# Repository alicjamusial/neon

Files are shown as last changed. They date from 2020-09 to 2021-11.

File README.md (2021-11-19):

# NEON - FT4232H Mini Module Adapter 

### about the project

 Neon is a PCB project designed as an adapter for FTDI FT4232H Mini Module board. It includes four two rows UART sockets (A, B, C, D) for easy plugging in logic analyzer and LEDs on both TX/RX and USB power supply. Its main goal is to improve the experience of using FTDI Mini Module and allow to quickly and easily debug any possible issues. It was designed using [KiCad](https://kicad.org/).

Version 1.0 is available [in the releases section](https://github.com/alicjamusial/neon/releases/tag/neon-v.1.0).

### usage
To be able to use Neon powered by USB two jumpers needs to be placed on the board (on J1 (3V3 & VIO) and J5 (VCC & VBUS) elements).

### license
Neon is available on Creative Commons Attribution Share Alike 4.0 International license (more in [license file](LICENSE.txt)). You are free to use it, modify it and produce as many of your own neons as you need :)

### assembled neon ✨

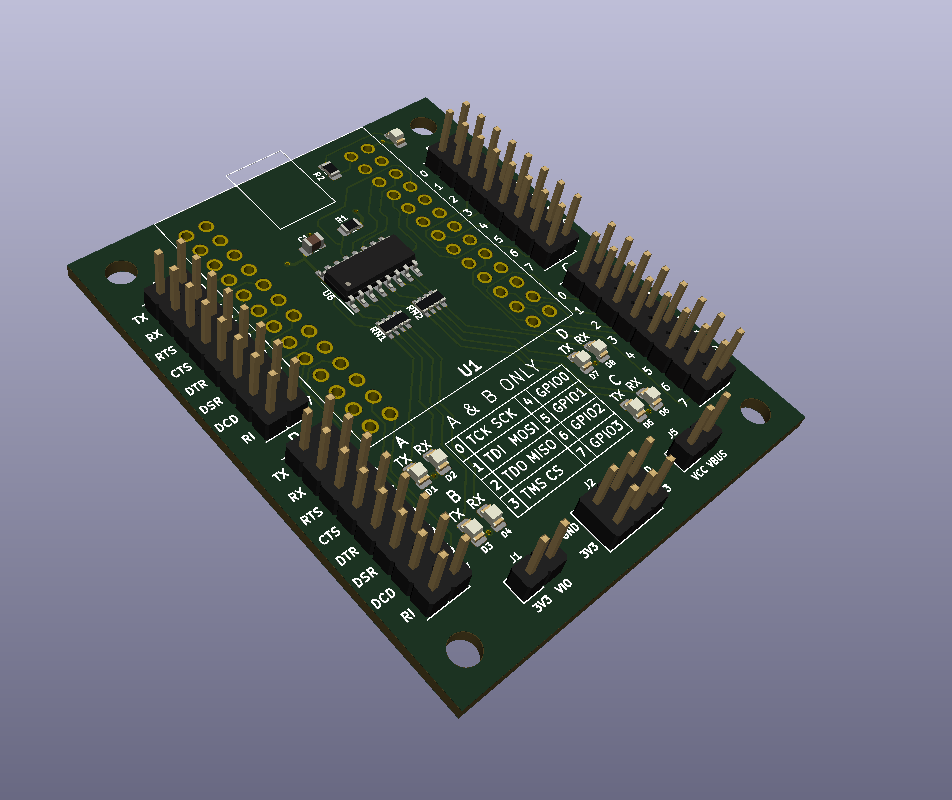
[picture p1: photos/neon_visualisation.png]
visualisation

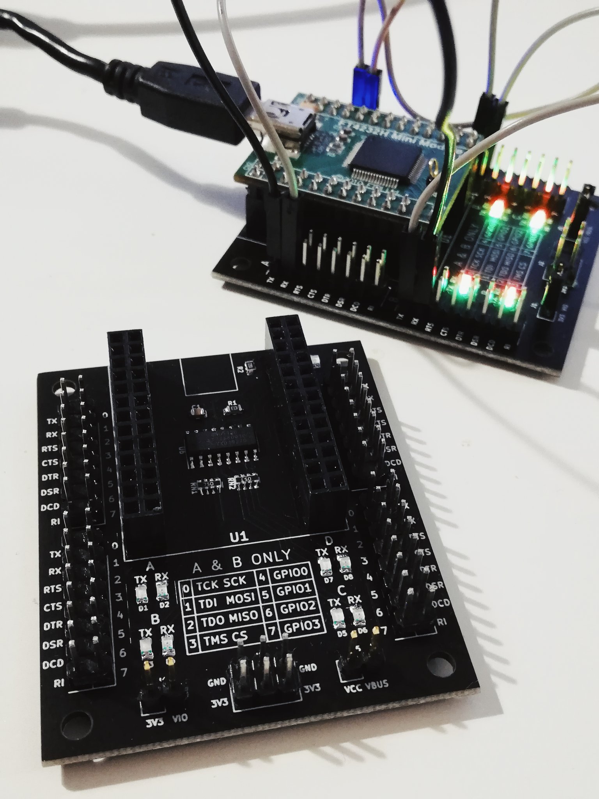
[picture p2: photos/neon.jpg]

gif

#### TODO in version 1.1
* label for D9 LED on board,
* labels for the directions of all LEDs on board,
* ...any ideas/fixes/improvements/PRs are welcomed :)

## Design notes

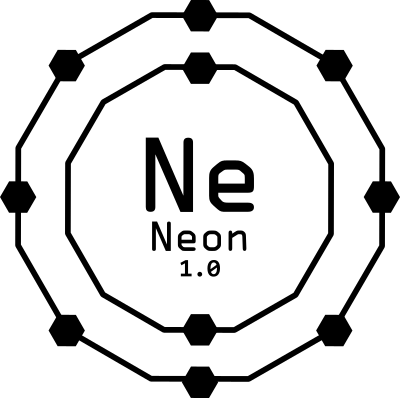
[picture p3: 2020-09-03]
NEON.png

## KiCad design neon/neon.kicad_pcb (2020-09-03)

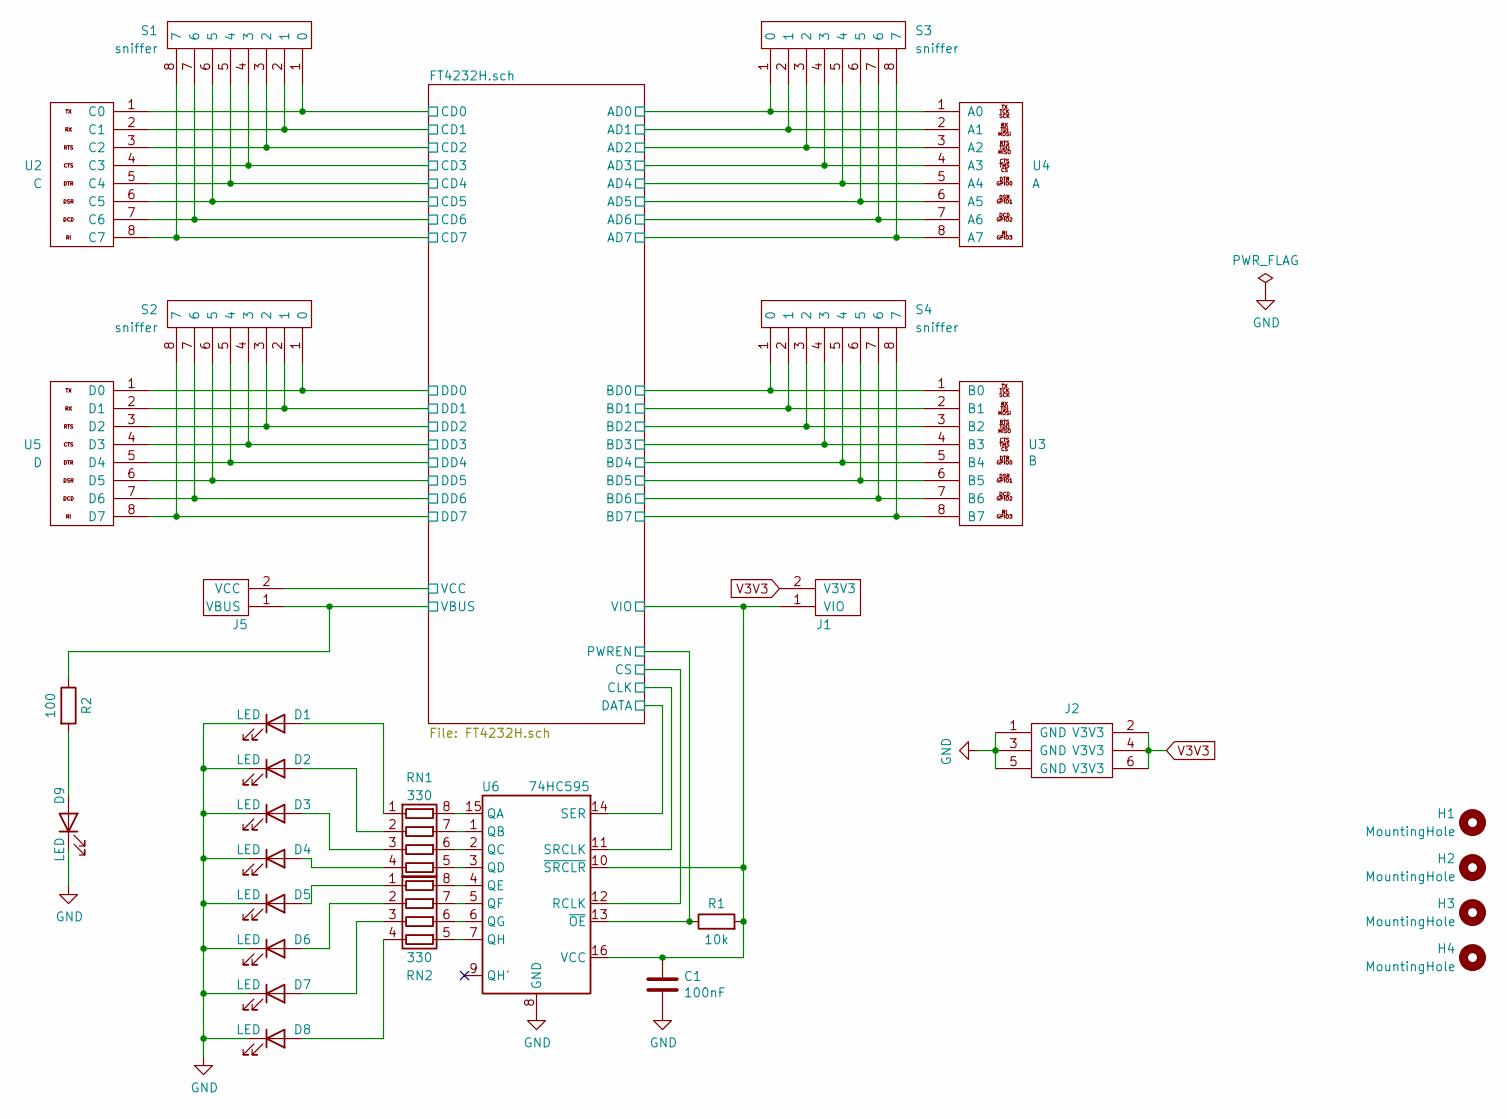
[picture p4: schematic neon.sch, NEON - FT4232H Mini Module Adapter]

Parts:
C1: 100nF; C_0805_2012Metric
D1, D2, D3, D4, D5, D6, D7, D8, D9: LED; LED_0805_2012Metric
H1, H2, H3, H4: MountingHole; MountingHole_3.2mm_M3
J1: V3V3-VIO; PinHeader_1x02_P2.54mm_Vertical
J2: 3xV3V3-GND; PinHeader_2x03_P2.54mm_Vertical
J5: VBUS-VCC; PinHeader_1x02_P2.54mm_Vertical
R1: 10k; R_0805_2012Metric
R2: 100; R_0805_2012Metric
RN1, RN2: 330; R_Array_Convex_4x0603
S1, S2, S3, S4: sniffer; PinHeader_1x08_P2.54mm_Vertical
U2: C; PinHeader_1x08_P2.54mm_Vertical
U3: B; PinHeader_1x08_P2.54mm_Vertical
U4: A; PinHeader_1x08_P2.54mm_Vertical
U5: D; PinHeader_1x08_P2.54mm_Vertical
U6: 74HC595; SOIC-16_3.9x9.9mm_P1.27mm

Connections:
/FT4232H.sch/AD0: S3.1 (0), U4.1 (A0); also elsewhere on the board
/FT4232H.sch/AD1: S3.2 (1), U4.2 (A1); also elsewhere on the board
/FT4232H.sch/AD2: S3.3 (2), U4.3 (A2); also elsewhere on the board
/FT4232H.sch/AD3: S3.4 (3), U4.4 (A3); also elsewhere on the board
/FT4232H.sch/AD4: S3.5 (4), U4.5 (A4); also elsewhere on the board
/FT4232H.sch/AD5: S3.6 (5), U4.6 (A5); also elsewhere on the board
/FT4232H.sch/AD6: S3.7 (6), U4.7 (A6); also elsewhere on the board
/FT4232H.sch/AD7: S3.8 (7), U4.8 (A7); also elsewhere on the board
/FT4232H.sch/BD0: S4.1 (0), U3.1 (B0); also elsewhere on the board
/FT4232H.sch/BD1: S4.2 (1), U3.2 (B1); also elsewhere on the board
/FT4232H.sch/BD2: S4.3 (2), U3.3 (B2); also elsewhere on the board
/FT4232H.sch/BD3: S4.4 (3), U3.4 (B3); also elsewhere on the board
/FT4232H.sch/BD4: S4.5 (4), U3.5 (B4); also elsewhere on the board
/FT4232H.sch/BD5: S4.6 (5), U3.6 (B5); also elsewhere on the board
/FT4232H.sch/BD6: S4.7 (6), U3.7 (B6); also elsewhere on the board
/FT4232H.sch/BD7: S4.8 (7), U3.8 (B7); also elsewhere on the board
/FT4232H.sch/CD0: S1.1 (0), U2.1 (C0); also elsewhere on the board
/FT4232H.sch/CD1: S1.2 (1), U2.2 (C1); also elsewhere on the board
/FT4232H.sch/CD2: S1.3 (2), U2.3 (C2); also elsewhere on the board
/FT4232H.sch/CD3: S1.4 (3), U2.4 (C3); also elsewhere on the board
/FT4232H.sch/CD4: S1.5 (4), U2.5 (C4); also elsewhere on the board
/FT4232H.sch/CD5: S1.6 (5), U2.6 (C5); also elsewhere on the board
/FT4232H.sch/CD6: S1.7 (6), U2.7 (C6); also elsewhere on the board
/FT4232H.sch/CD7: S1.8 (7), U2.8 (C7); also elsewhere on the board
/FT4232H.sch/CLK: U6.11 (SRCLK); also elsewhere on the board
/FT4232H.sch/CS: U6.12 (RCLK); also elsewhere on the board
/FT4232H.sch/DATA: U6.14 (SER); also elsewhere on the board
/FT4232H.sch/DD0: S2.1 (0), U5.1 (D0); also elsewhere on the board
/FT4232H.sch/DD1: S2.2 (1), U5.2 (D1); also elsewhere on the board
/FT4232H.sch/DD2: S2.3 (2), U5.3 (D2); also elsewhere on the board
/FT4232H.sch/DD3: S2.4 (3), U5.4 (D3); also elsewhere on the board
/FT4232H.sch/DD4: S2.5 (4), U5.5 (D4); also elsewhere on the board
/FT4232H.sch/DD5: S2.6 (5), U5.6 (D5); also elsewhere on the board
/FT4232H.sch/DD6: S2.7 (6), U5.7 (D6); also elsewhere on the board
/FT4232H.sch/DD7: S2.8 (7), U5.8 (D7); also elsewhere on the board
/FT4232H.sch/PWREN: R1.1, U6.13 (~OE); also elsewhere on the board
/FT4232H.sch/VBUS: J5.1 (VBUS), R2.1; also elsewhere on the board
/FT4232H.sch/VCC: J5.2 (VCC); also elsewhere on the board
/FT4232H.sch/VIO: C1.1, J1.1 (VIO), R1.2, U6.10 (~SRCLR), U6.16 (VCC); also elsewhere on the board
GND: C1.2, D1.1 (K), D2.1 (K), D3.1 (K), D4.1 (K), D5.1 (K), D6.1 (K), D7.1 (K), D8.1 (K), D9.1 (K), J2.1 (GND), J2.3 (GND), J2.5 (GND), U6.8 (GND); also elsewhere on the board
unnamed: D1.2 (A), RN1.1 (R1.1)
unnamed: D2.2 (A), RN1.2 (R2.1)
unnamed: D3.2 (A), RN1.3 (R3.1)
unnamed: D4.2 (A), RN1.4 (R4.1)
unnamed: D5.2 (A), RN2.1 (R1.1)
unnamed: D6.2 (A), RN2.2 (R2.1)
unnamed: D7.2 (A), RN2.3 (R3.1)
unnamed: D8.2 (A), RN2.4 (R4.1)
unnamed: D9.2 (A), R2.2
unnamed: RN1.5 (R4.2), U6.3 (QD)
unnamed: RN1.6 (R3.2), U6.2 (QC)
unnamed: RN1.7 (R2.2), U6.1 (QB)
unnamed: RN1.8 (R1.2), U6.15 (QA)
unnamed: RN2.5 (R4.2), U6.7 (QH)
unnamed: RN2.6 (R3.2), U6.6 (QG)
unnamed: RN2.7 (R2.2), U6.5 (QF)
unnamed: RN2.8 (R1.2), U6.4 (QE)
V3V3: J1.2 (V3V3), J2.2 (V3V3), J2.4 (V3V3), J2.6 (V3V3); also elsewhere on the board

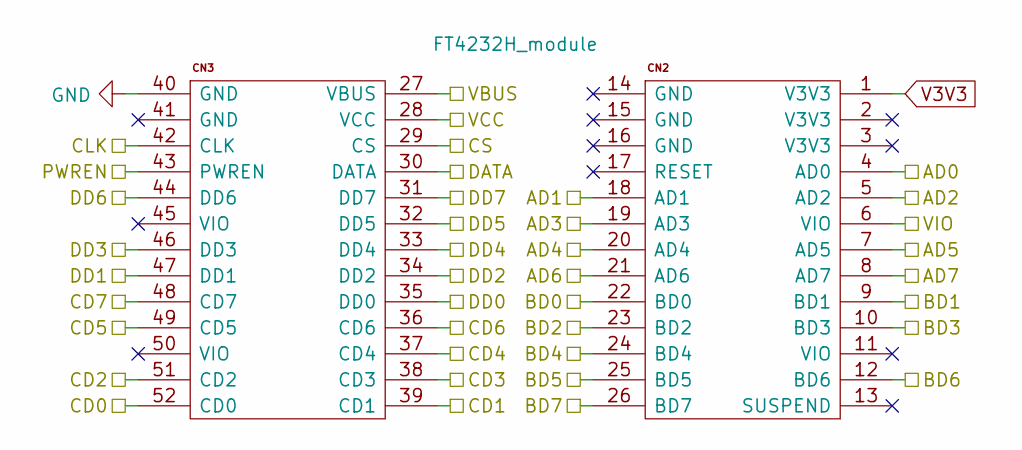
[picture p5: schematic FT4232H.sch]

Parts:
U1: FT4232H_module; FT4232H-MINI-MODULE-2

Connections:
/FT4232H.sch/AD0: U1.4 (AD0); also elsewhere on the board
/FT4232H.sch/AD1: U1.18 (AD1); also elsewhere on the board
/FT4232H.sch/AD2: U1.5 (AD2); also elsewhere on the board
/FT4232H.sch/AD3: U1.19 (AD3); also elsewhere on the board
/FT4232H.sch/AD4: U1.20 (AD4); also elsewhere on the board
/FT4232H.sch/AD5: U1.7 (AD5); also elsewhere on the board
/FT4232H.sch/AD6: U1.21 (AD6); also elsewhere on the board
/FT4232H.sch/AD7: U1.8 (AD7); also elsewhere on the board
/FT4232H.sch/BD0: U1.22 (BD0); also elsewhere on the board
/FT4232H.sch/BD1: U1.9 (BD1); also elsewhere on the board
/FT4232H.sch/BD2: U1.23 (BD2); also elsewhere on the board
/FT4232H.sch/BD3: U1.10 (BD3); also elsewhere on the board
/FT4232H.sch/BD4: U1.24 (BD4); also elsewhere on the board
/FT4232H.sch/BD5: U1.25 (BD5); also elsewhere on the board
/FT4232H.sch/BD6: U1.12 (BD6); also elsewhere on the board
/FT4232H.sch/BD7: U1.26 (BD7); also elsewhere on the board
/FT4232H.sch/CD0: U1.52 (CD0); also elsewhere on the board
/FT4232H.sch/CD1: U1.39 (CD1); also elsewhere on the board
/FT4232H.sch/CD2: U1.51 (CD2); also elsewhere on the board
/FT4232H.sch/CD3: U1.38 (CD3); also elsewhere on the board
/FT4232H.sch/CD4: U1.37 (CD4); also elsewhere on the board
/FT4232H.sch/CD5: U1.49 (CD5); also elsewhere on the board
/FT4232H.sch/CD6: U1.36 (CD6); also elsewhere on the board
/FT4232H.sch/CD7: U1.48 (CD7); also elsewhere on the board
/FT4232H.sch/CLK: U1.42 (CLK); also elsewhere on the board
/FT4232H.sch/CS: U1.29 (CS); also elsewhere on the board
/FT4232H.sch/DATA: U1.30 (DATA); also elsewhere on the board
/FT4232H.sch/DD0: U1.35 (DD0); also elsewhere on the board
/FT4232H.sch/DD1: U1.47 (DD1); also elsewhere on the board
/FT4232H.sch/DD2: U1.34 (DD2); also elsewhere on the board
/FT4232H.sch/DD3: U1.46 (DD3); also elsewhere on the board
/FT4232H.sch/DD4: U1.33 (DD4); also elsewhere on the board
/FT4232H.sch/DD5: U1.32 (DD5); also elsewhere on the board
/FT4232H.sch/DD6: U1.44 (DD6); also elsewhere on the board
/FT4232H.sch/DD7: U1.31 (DD7); also elsewhere on the board
/FT4232H.sch/PWREN: U1.43 (PWREN); also elsewhere on the board
/FT4232H.sch/VBUS: U1.27 (VBUS); also elsewhere on the board
/FT4232H.sch/VCC: U1.28 (VCC); also elsewhere on the board
/FT4232H.sch/VIO: U1.6 (VIO); also elsewhere on the board
GND: U1.40 (GND); also elsewhere on the board
V3V3: U1.1 (V3V3); also elsewhere on the board

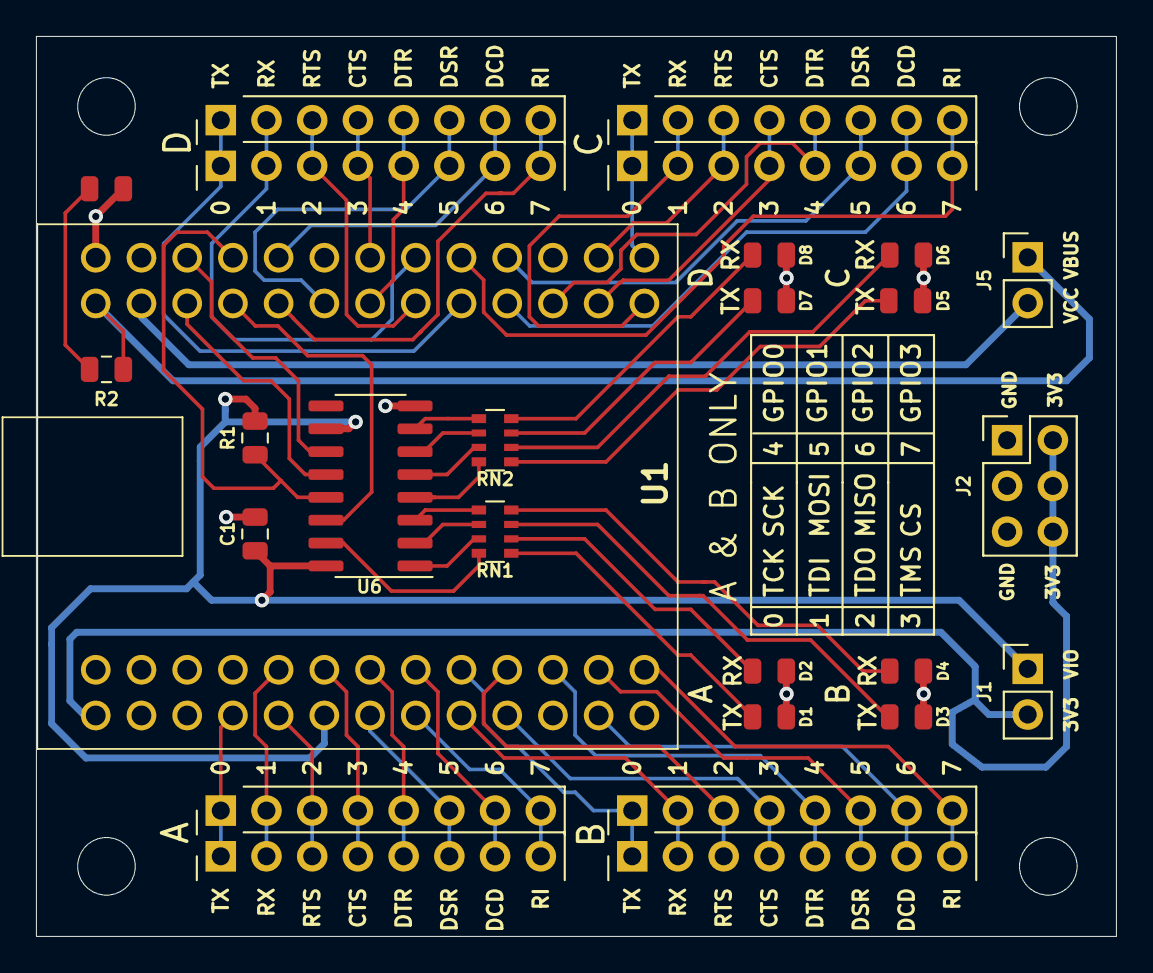
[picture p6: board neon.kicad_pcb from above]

Board: 2 copper layers, 60.0 x 50.0 mm, 31 parts (0 on the bottom side), 58 nets.

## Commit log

2020-08-29 Repo init
    [neon.kicad_pcb, neon.sch]
2020-08-29 Add FT4232H module pinouts
    [neon.sch]
2020-08-29 Hierarchical version - draft
    [FT4232H.sch, neon.sch]
2020-08-29 Add all hierarchical pins
    [FT4232H.sch, neon.sch]
2020-08-29 Add more hierarchical pins
    [FT4232H.sch, neon.sch]
2020-08-29 B, C & D buses
    [neon.sch]
2020-08-30 V3V3 & GND pings
    [neon.sch]
2020-08-30 Add LEDs
    [FT4232H.sch, neon.sch]
2020-08-30 Annotate components
    [neon.sch]
2020-08-30 Assign footprints - part 1 and buggy
    [FT4232H.sch, neon.kicad_pcb, neon.sch]
2020-08-30 Pin warning fixes
    [FT4232H.sch, neon.sch]
2020-08-30 Order pins on footprint - part 1
    [neon.kicad_pcb]
2020-08-30 Order pins on footprint - part 2
    [neon.kicad_pcb, neon.sch]
2020-08-30 Board cuts - part 1
    [neon.kicad_pcb]
2020-08-30 FTDI centered (almost)
    [neon.kicad_pcb]
2020-08-30 Restore lost pin
    [neon.kicad_pcb, neon.sch]
2020-08-30 Labels adjustments
    [neon.kicad_pcb]
2020-08-30 Remove bak
    [neon.kicad_pcb]
2020-08-30 With transistors
    [neon.kicad_pcb, neon.sch]
2020-08-30 Version with shift register - schematic
    [FT4232H.sch, neon.kicad_pcb, neon.sch]
2020-08-30 Assign LEDs on pcb
    [neon.kicad_pcb]
2020-08-30 A BUS
    [neon.kicad_pcb]
2020-08-31 Texts ideas
    [neon.kicad_pcb, neon.sch]
2020-08-31 More labels
    [neon.kicad_pcb]
2020-08-31 Labels four versions
    [neon.kicad_pcb]
2020-08-31 With table and LEDs underneath the ftdi
    [neon.kicad_pcb]
2020-09-01 Add sniffer
    [FT4232H.sch, neon.sch]
2020-09-01 Sniffer PCB - draft
    [neon.kicad_pcb, neon.sch]
2020-09-01 All sniffers on PCB
    [neon.kicad_pcb, neon.sch]
2020-09-01 Problems fixes
    [neon.kicad_pcb, neon.sch]
2020-09-01 Center things & rotate J1 & J5
    [neon.kicad_pcb]
2020-09-01 A, B, C & D distances
    [neon.kicad_pcb]
2020-09-02 Add 3x2 connector for GND&3v3
    [neon.kicad_pcb, neon.sch]
2020-09-02 Add LED to VBUS
    [neon.sch]
2020-09-02 Bigger letters & remove random dot
    [neon.kicad_pcb, neon.sch]
2020-09-02 Small fixes
    [neon.kicad_pcb]
2020-09-02 Move LED, fix H4&H2 and some paths
    [neon.kicad_pcb]
2020-09-02 Move register & some paths
    [neon.kicad_pcb]
2020-09-02 Buses paths
    [neon.kicad_pcb]
2020-09-02 A & B buses
    [neon.kicad_pcb]
2020-09-02 LEDs paths
    [neon.kicad_pcb]
2020-09-02 C paths
    [neon.kicad_pcb]
2020-09-02 Fix for Maciek's OCD
    [neon.kicad_pcb]
2020-09-02 D bus
    [neon.kicad_pcb]
2020-09-03 Fix nets width
    [neon.kicad_pcb, neon.sch]
2020-09-03 Draw all nets
    [neon.kicad_pcb]
2020-09-03 Fill GND plane
    [neon.kicad_pcb]
2020-09-03 Add logo
    [neon.kicad_pcb]
2020-09-03 Fix nets too close to pads
    [neon.kicad_pcb]
2021-11-09 Update README.md
    https://forum.kicad.info/t/warning-avoid-all-links-to-kicad-pcb-org-use-kicad-org/31521
